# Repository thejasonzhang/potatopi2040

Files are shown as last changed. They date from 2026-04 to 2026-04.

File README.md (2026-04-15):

PotatoPi
Overview

PotatoPi is a custom RP2040-based devboard that can be used for lots of cool hardware and software projects.
It follows the same pinout as the Raspberry Pi Pico and is fully feature-compatible.

It will also include headers soldered on.

- Features
- 16MB onboard flash memory
- Convenient reset button for easy flashing
- Custom PotatoPi artwork on both sides of the PCB
- All components hand soldered (no PCBA)

I made this to get back into hardware and to redeem myself from my last project.
I also wanted to try out SMD soldering.
The board will use a hot plate to do most of the reflow work and then an iron to fix any mistakes and add the ehaders.

Gallery

Front & board renders as well as Potato Pi illustrations:

 

Bill of Materials (BOM)

| **Category** | **Designator / Item** | **Footprint / Description** | **Qty** | **Value / Part** | **Link** | **Cost** |
| --- | --- | --- | --- | --- | --- | --- |
| Capacitor | C1, C12 | 402 | 2 | 1µF | [https://www.lcsc.com/product-detail/C29266.html](https://www.lcsc.com/product-detail/C29266.html) | 0.26 |
| Capacitor | C10–C11, C17, C2–C9 | 402 | 11 | 0.1µF | [https://www.lcsc.com/product-detail/C1525.html](https://www.lcsc.com/product-detail/C1525.html) | 0.13 |
| Capacitor | C13, C14 | 603 | 2 | 10µF | [https://www.lcsc.com/product-detail/C19702.html](https://www.lcsc.com/product-detail/C19702.html) | 0.40 |
| Capacitor | C15, C16 | 603 | 2 | 33pF | [https://www.lcsc.com/product-detail/C107047.html](https://www.lcsc.com/product-detail/C107047.html) | 0.30 |
| Connector | J1 | USB-C Receptacle | 1 | USB 2.0 14P | [https://www.lcsc.com/product-detail/C165948.html](https://www.lcsc.com/product-detail/C165948.html) | 0.85 |
| Connector | J2, J3 | Pin Header 1x20 | 2 | Conn_01x20 | [https://www.lcsc.com/product-detail/C42431804.html](https://www.lcsc.com/product-detail/C42431804.html) | 0.46 |
| Connector | J4 | Pin Header 1x03 | 1 | Conn_01x03 | [https://www.lcsc.com/product-detail/C32713269.html](https://www.lcsc.com/product-detail/C32713269.html) | 0.11 |
| Resistor | R1, R2 | 402 | 2 | 5.1kΩ | [https://www.lcsc.com/product-detail/C25905.html](https://www.lcsc.com/product-detail/C25905.html) | 0.08 |
| Resistor | R3, R4 | 402 | 2 | 27Ω | [https://www.lcsc.com/product-detail/C25100.html](https://www.lcsc.com/product-detail/C25100.html) | 0.08 |
| Resistor | R5, R6 | 402 | 2 | 1kΩ | [https://www.lcsc.com/product-detail/C11702.html](https://www.lcsc.com/product-detail/C11702.html) | 0.07 |
| Resistor | R7 | 402 | 1 | 10kΩ | [https://www.lcsc.com/product-detail/C60490.html](https://www.lcsc.com/product-detail/C60490.html) | 0.08 |
| Switch | SW1 | Push Button | 1 | Momentary | [https://www.lcsc.com/product-detail/C720477.html](https://www.lcsc.com/product-detail/C720477.html) | 0.55 |
| IC | U1 | QFN-56 | 1 | RP2040 | [https://www.lcsc.com/product-detail/C2040.html](https://www.lcsc.com/product-detail/C2040.html) | 0.95 |
| IC | U2 | SOT-23 | 1 | MCP1700-3302 | [https://www.lcsc.com/product-detail/C39051.html](https://www.lcsc.com/product-detail/C39051.html) | 2.45 |
| IC | U3 | USON-8 | 1 | W25Q16JV | [https://www.lcsc.com/product-detail/C2456208.html](https://www.lcsc.com/product-detail/C2456208.html) | 1.31 |
| Crystal | Y1 | 3225 | 1 | 12 MHz | [https://www.lcsc.com/product-detail/C9002.html](https://www.lcsc.com/product-detail/C9002.html) | 0.73 |
| Service | PCB | JLCPCB fabrication | 1 | Manufacturing | [https://cart.jlcpcb.com/quote/gerberviewThree/?qs=d00311a2c2824fc7aa7ee1bc072ff726_1_0_1_0_0.html] | 2.10 |
| Tool | Tip | T18-D24 solder tip | 1 | Hakko chisel | [https://www.microcenter.com/product/658966/hakko-t18-series-006-in-chisel-tip] | 6.99 |
| Tool | Wick | Desolder wick | 1 | iFixit wick |[https://www.microcenter.com/product/693022/ifixit-desoldering-wick] | 4.99 |
| Tool | Tweezers | Curved ESD | 1 | precision | [https://www.microcenter.com/product/361636/enkay-products-heat-resistant-soldering-tweezers-curved-point] | 2.99 |
| Tool | Helping Hand | Magnifier stand | 1 | third hand |[https://www.microcenter.com/product/618902/inland-inland-adjustable-helping-hand-w-magnifying-glass] | 4.99 |
Cost Summary
Subtotal: $30.87
Shipping: $15.24
Tax: $3.82
TOTAL: $49.93

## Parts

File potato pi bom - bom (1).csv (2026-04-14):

Designator | Footprint | Quantity | Value | link | Unir Cost | Cost | Column 1
C1, C12 | 402 | 2 | 1uF | https://www.lcsc.com/product-detail/C29266.html?s_z=n_1uF | 0.0026*100=0.26 | 0.26 | TRUE
C10, C11, C17, C2, C3, C4, C5, C6, C7, C8, C9 | 402 | 11 | 0.1uF | https://www.lcsc.com/product-detail/C1525.html?s_z=n_CL05B104KO5NNNC | 0.0013*100=0.13 | 0.13 | TRUE
C13, C14 | 603 | 2 | 10uF | https://www.lcsc.com/product-detail/C19702.html?s_z=n_10uF | 0.008*50=0.4 | 0.4 | TRUE
C15, C16 | 603 | 2 | 33pF | https://www.lcsc.com/product-detail/C107047.html?s_z=n_33pF | 0.003*100=0.3 | 0.3 | TRUE
J1 | USB_C_Receptacle_HRO_TYPE-C-31-M-12 | 1 | USB_C_Receptacle_USB2.0_14P | https://www.lcsc.com/product-detail/C165948.html?s_z=n_TYPE-C-31-M-12 | 0.17*5=0.85 | 0.85 | TRUE
J2, J3 | PinHeader_1x20_P2.54mm_Vertical | 2 | Conn_01x20 | https://www.lcsc.com/product-detail/C42431804.html?s_z=n_1x20 | 0.092*5=0.46 | 0.46 | TRUE
J4 | PinHeader_1x03_P2.54mm_Vertical | 1 | Conn_01x03 | https://www.lcsc.com/product-detail/C32713269.html?s_z=n_1x3%25202.54mm | 0.0228*5=0.11 | 0.11 | TRUE
R1, R2 | 402 | 2 | 5.1K | https://www.lcsc.com/product-detail/C25905.html?s_z=n_0402WGF5101TCE | 0.0008*100=0.08 | 0.08 | TRUE
R3, R4 | 402 | 2 | 27ohm | https://www.lcsc.com/product-detail/C25100.html?s_z=n_27ohm | 0.0008*100=0.08 | 0.08 | TRUE
R5, R6 | 402 | 2 | 1K | https://www.lcsc.com/product-detail/C11702.html?s_z=n_0402WGF1001TCE | 0.0007*100=0.07 | 0.07 | TRUE
R7 | 402 | 1 | 10K | https://www.lcsc.com/product-detail/C60490.html?s_z=n_10k%25CE%25A9%2520 | 0.0008*100=0.08 | 0.08 | TRUE
SW1 | SW_Push_SPST_NO_Alps_SKRK | 1 | SW_Push | https://www.lcsc.com/product-detail/C720477.html?s_z=n_TS-1088-AR02016 | 0.055*10=0.55 | 0.55 | TRUE
U1 | QFN-56-1EP_7x7mm_P0.4mm_EP3.2x3.2mm | 1 | RP2040 | https://www.lcsc.com/product-detail/C2040.html?s_z=n_rp2040 | 0.95 | 0.95 | TRUE
U2 | SOT-23 | 1 | MCP1700x-330xxTT | https://www.lcsc.com/product-detail/C39051.html?s_z=n_MCP1700T-3302E%252FTT | 0.49*5=2.45 | 2.45 | TRUE
U3 | Winbond_USON-8-1EP_3x2mm_P0.5mm_EP0.2x1.6mm | 1 | W25Q16JVZPIQ TR | https://www.lcsc.com/product-detail/C2456208.html?s_z=n_W25Q16JVZPIQ%2520TR | 1.31 | 1.31 | TRUE
Y1 | Crystal_SMD_3225-4Pin_3.2x2.5mm | 1 | 12 MHz | https://www.lcsc.com/product-detail/C9002.html?s_z=n_X322512MSB4SI | 0.073*10=0.73 | 0.73 | TRUE
 | JLCPCB | 1 |  | https://cart.jlcpcb.com/quote/gerberviewThree/?qs=a23e7f3868a44292b2bc773764c7d804_1_0_4_0_0.html | 2.1 | 2.1 | TRUE
 | T18-D24 Tip | 1 |  | Hakko T18 Series 0.09 in. Chisel Tip - Micro Center | 6.99 | 6.99 | TRUE
 | Wick | 1 |  | iFixit Desoldering Wick - Micro Center | 4.99 | 4.99 | TRUE
 | Rosin Flux | n/a |  | CAIG Laboratories DeoxIT Brand No Clean RMA Soldering Flux in Syringe Applicator - Micro Center | 7.99 | 0 | TRUE
 | Tweezers | 1 |  | https://www.microcenter.com/product/361636/enkay-products-heat-resistant-soldering-tweezers-curved-point | 2.99 | 2.99 | TRUE
 | Helping Hand and Magnifying Glass | 1 |  | Inland Inland Adjustable Helping Hand w/ Magnifying Glass - Micro Center | 4.99 | 4.99 | TRUE
 |  |  |  |  | Subtotal
 |  |  |  |  |  | 30.87
 |  |  |  |  | Shipping and Handling
 |  |  |  |  | LCSC | 12.12
 |  |  |  |  | JLCPCB | 3.12
 |  |  |  |  | Tax
 |  |  |  |  | Micro Center | 3.82
 |  |  |  |  | Total
 |  |  |  |  |  | 49.93

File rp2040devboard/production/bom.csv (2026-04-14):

Designator | Footprint | Quantity | Value | LCSC Part #
C1, C12 | 0402 | 2 | 1uF
C10, C11, C17, C2, C3, C4, C5, C6, C7, C8, C9 | 0402 | 11 | 0.1uF
C13, C14 | 0603 | 2 | 10uF
C15, C16 | 0603 | 2 | 33pF
J1 | USB_C_Receptacle_HRO_TYPE-C-31-M-12 | 1 | USB_C_Receptacle_USB2.0_14P
J2, J3 | PinHeader_1x20_P2.54mm_Vertical | 2 | Conn_01x20
J4 | PinHeader_1x03_P2.54mm_Vertical | 1 | Conn_01x03
R1, R2 | 0402 | 2 | 5.1K
R3, R4 | 0402 | 2 | 27
R5, R6 | 0402 | 2 | 1K
R7 | 0402 | 1 | 10K
SW1 | SW_Push_SPST_NO_Alps_SKRK | 1 | SW_Push
U1 | QFN-56-1EP_7x7mm_P0.4mm_EP3.2x3.2mm | 1 | RP2040
U2 | SOT-23 | 1 | MCP1700x-330xxTT
U3 | Winbond_USON-8-1EP_3x2mm_P0.5mm_EP0.2x1.6mm | 1 | W25Q16JVZPIQ TR
Y1 | Crystal_SMD_3225-4Pin_3.2x2.5mm | 1 | 12 MHz

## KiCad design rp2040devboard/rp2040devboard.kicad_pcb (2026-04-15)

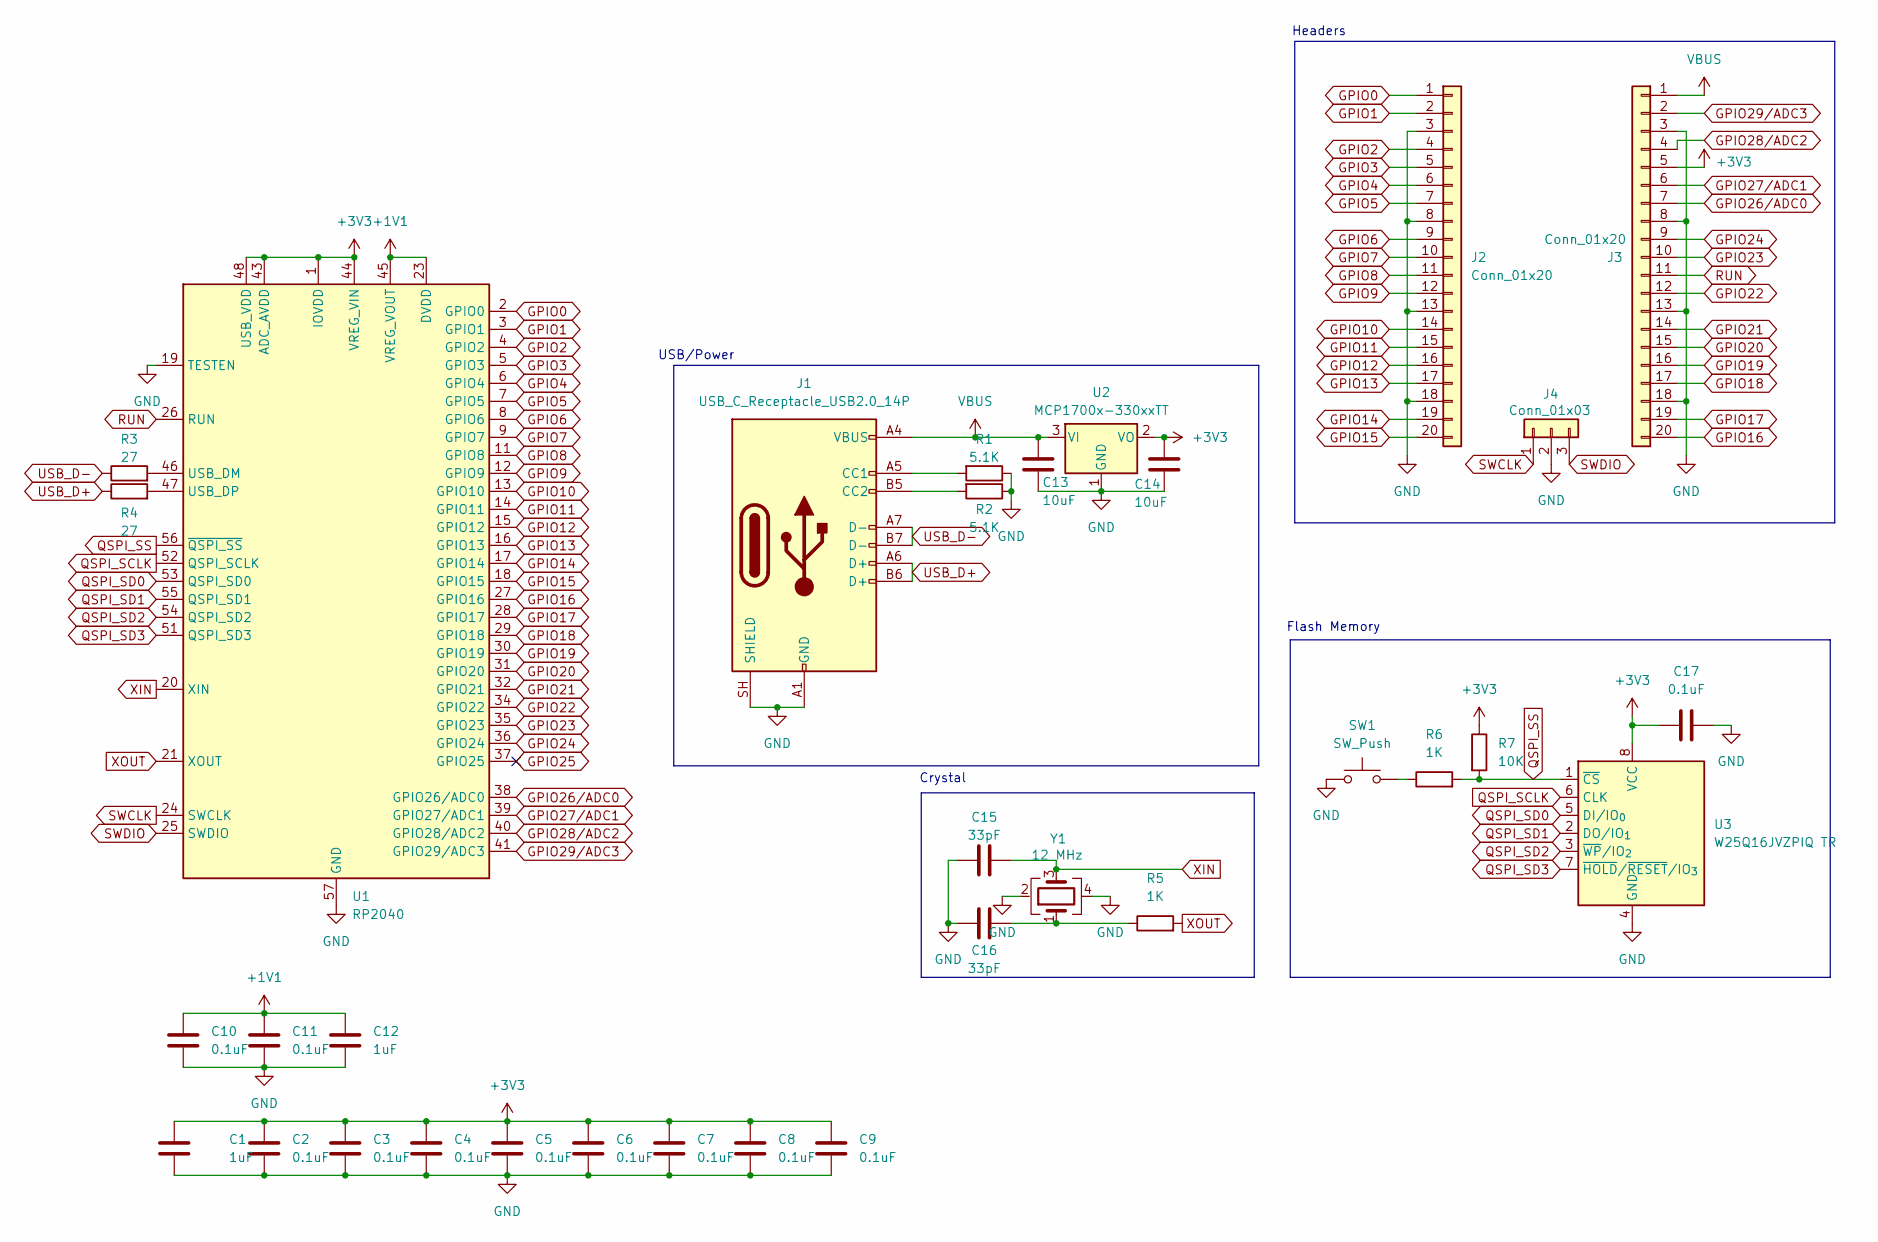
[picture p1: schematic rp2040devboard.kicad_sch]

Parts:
C1, C12: 1uF; C_0402_1005Metric
C2, C3, C4, C5, C6, C7, C8, C9, C10, C11, C17: 0.1uF; C_0402_1005Metric
C13, C14: 10uF; C_0603_1608Metric
C15, C16: 33pF; C_0603_1608Metric
J1: USB_C_Receptacle_USB2.0_14P; USB_C_Receptacle_HRO_TYPE-C-31-M-12
J2, J3: Conn_01x20; PinHeader_1x20_P2.54mm_Vertical
J4: Conn_01x03; PinHeader_1x03_P2.54mm_Vertical
R1, R2: 5.1K; R_0402_1005Metric
R3, R4: 27; R_0402_1005Metric
R5, R6: 1K; R_0402_1005Metric
R7: 10K; R_0402_1005Metric
SW1: SW_Push; SW_Push_SPST_NO_Alps_SKRK
U1: RP2040; QFN-56-1EP_7x7mm_P0.4mm_EP3.2x3.2mm
U2: MCP1700x-330xxTT; SOT-23
U3: W25Q16JVZPIQ TR; Winbond_USON-8-1EP_3x2mm_P0.5mm_EP0.2x1.6mm
Y1: 12 MHz; Crystal_SMD_3225-4Pin_3.2x2.5mm

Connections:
+1V1: C10.1, C11.1, C12.1, U1.23 (DVDD), U1.45 (VREG_VOUT), U1.50 (DVDD)
+3V3: C1.1, C2.1, C3.1, C4.1, C5.1, C6.1, C7.1, C8.1, C9.1, C14.1, C17.2, J3.5, R7.1, U1.1 (IOVDD), U1.10 (IOVDD), U1.22 (IOVDD), U1.33 (IOVDD), U1.42 (IOVDD), U1.43 (ADC_AVDD), U1.44 (VREG_VIN), U1.48 (USB_VDD), U1.49 (IOVDD), U2.2 (VO), U3.8 (VCC)
GND: C1.2, C2.2, C3.2, C4.2, C5.2, C6.2, C7.2, C8.2, C9.2, C10.2, C11.2, C12.2, C13.1, C14.2, C15.1, C16.1, C17.1, J1.A1 (GND), J1.A12 (GND), J1.B1 (GND), J1.B12 (GND), J1.SH (SHIELD), J2.3, J2.8, J2.13, J2.18, J3.3, J3.8, J3.13, J3.18, J4.2, R1.1, R2.1, SW1.1, U1.19 (TESTEN), U1.57 (GND), U2.1 (GND), U3.4 (GND), Y1.2 (G), Y1.4 (G)
GPIO0: J2.1, U1.2 (GPIO0)
GPIO1: J2.2, U1.3 (GPIO1)
GPIO2: J2.4, U1.4 (GPIO2)
GPIO3: J2.5, U1.5 (GPIO3)
GPIO4: J2.6, U1.6 (GPIO4)
GPIO5: J2.7, U1.7 (GPIO5)
GPIO6: J2.9, U1.8 (GPIO6)
GPIO7: J2.10, U1.9 (GPIO7)
GPIO8: J2.11, U1.11 (GPIO8)
GPIO9: J2.12, U1.12 (GPIO9)
GPIO10: J2.14, U1.13 (GPIO10)
GPIO11: J2.15, U1.14 (GPIO11)
GPIO12: J2.16, U1.15 (GPIO12)
GPIO13: J2.17, U1.16 (GPIO13)
GPIO14: J2.19, U1.17 (GPIO14)
GPIO15: J2.20, U1.18 (GPIO15)
GPIO16: J3.20, U1.27 (GPIO16)
GPIO17: J3.19, U1.28 (GPIO17)
GPIO18: J3.17, U1.29 (GPIO18)
GPIO19: J3.16, U1.30 (GPIO19)
GPIO20: J3.15, U1.31 (GPIO20)
GPIO21: J3.14, U1.32 (GPIO21)
GPIO22: J3.12, U1.34 (GPIO22)
GPIO23: J3.10, U1.35 (GPIO23)
GPIO24: J3.9, U1.36 (GPIO24)
GPIO25: U1.37 (GPIO25)
GPIO26/ADC0: J3.7, U1.38 (GPIO26/ADC0)
GPIO27/ADC1: J3.6, U1.39 (GPIO27/ADC1)
GPIO28/ADC2: J3.4, U1.40 (GPIO28/ADC2)
GPIO29/ADC3: J3.2, U1.41 (GPIO29/ADC3)
unnamed: C16.2, R5.1, Y1.1
unnamed: J1.A5 (CC1), R1.2
unnamed: J1.B5 (CC2), R2.2
unnamed: R6.1, SW1.2
unnamed: R3.2, U1.46 (USB_DM)
unnamed: R4.2, U1.47 (USB_DP)
QSPI_SCLK: U1.52 (QSPI_SCLK), U3.6 (CLK)
QSPI_SD0: U1.53 (QSPI_SD0), U3.5 (DI/IO_{0})
QSPI_SD1: U1.55 (QSPI_SD1), U3.2 (DO/IO_{1})
QSPI_SD2: U1.54 (QSPI_SD2), U3.3 (~WP/IO_{2})
QSPI_SD3: U1.51 (QSPI_SD3), U3.7 (~HOLD/~RESET/IO_{3})
QSPI_SS: R6.2, R7.2, U1.56 (~QSPI_SS), U3.1 (~CS)
RUN: J3.11, U1.26 (RUN)
SWCLK: J4.1, U1.24 (SWCLK)
SWDIO: J4.3, U1.25 (SWDIO)
USB_D+: J1.A6 (D+), J1.B6 (D+), R4.1
USB_D-: J1.A7 (D-), J1.B7 (D-), R3.1
VBUS: C13.2, J1.A4 (VBUS), J1.A9 (VBUS), J1.B4 (VBUS), J1.B9 (VBUS), J3.1, U2.3 (VI)
XIN: C15.2, U1.20 (XIN), Y1.3
XOUT: R5.2, U1.21 (XOUT)

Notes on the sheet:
USB/Power
Crystal
Flash Memory
Headers

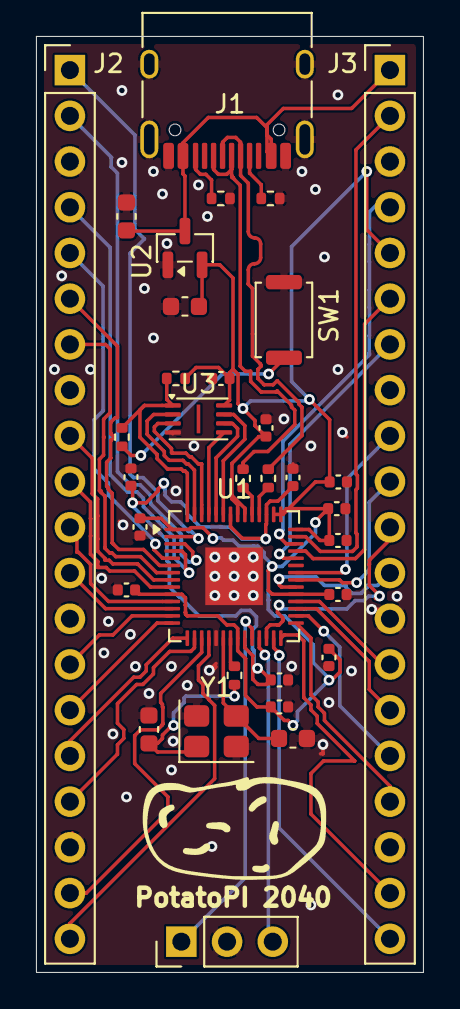
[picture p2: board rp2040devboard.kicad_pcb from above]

Board: 2 copper layers, 21.5 x 52.0 mm, 33 parts (0 on the bottom side), 52 nets.
